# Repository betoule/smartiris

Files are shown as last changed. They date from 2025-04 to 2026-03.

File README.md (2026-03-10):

SmartIris USB-Powered Shutter Controller
========================================

A compact and efficient USB-powered controller designed to handle two
independent Iris shutters by
[Thorlabs](https://www.thorlabs.com/newgrouppage9.cfm?objectgroup_id=6619&pn=SHB1T#7096). This
project offers an alternative solution that avoids heat dissipation,
sending only the necessary current pulses to open or close the
shutter. This alternative is suitable for low actuation rates (~1Hz), where timing accuracy matters.

Features
--------

* Easy-to-use USB interface for power and control
* Open-source design for customization
* Programmable coordinated channels for two Iris shutters
* Python library
* Improved energy efficiency by avoiding continuous heat dissipation
* Internal clock calibration for accurate timings
* Half-microsecond resolution on timings
* Timing of the iris movements via sensor feedback
* Echo the sensor feedback signal on a trig-out line
* Possibility to echo the pulse commands on the trig-out line

Getting Started
---------------

### Requirements

* One or Two Thorlabs Iris shutters
* USB A to Mini-B cable
* 3D printed or custom PCB case (optional)

### Software Installation

1. Download and install the control software for your operating system from the project's GitHub repository:
```bash
git clone https://github.com/betoule/smartiris.git
cd smartiris
pip install .
```
2. Connect the controller to your computer via a USB port using a USB A to Mini-B cable.
3. Ensure that an Iris shutters is properly connected to the controller with matching channel assignments. Port "A" and "B" refers to the left and right port respectively.
4. Test the status:
```bash
smartiris status
```
Example output for two closed and connected shutters:
```
{'shutter_A': 'closed', 'shutter_B': 'closed', 'busy': False}
```

Unconnected shutters appear as `closed`. Partly open shutters may appear as closed or open depending on the sensor location on the device.

The button can be used to switch the shutters on and off. They have precedence upon the software control, meaning that if a timed exposure as been programmed, pressing any of the button will interrupt the program and close or open the corresponding shutter. If needed button can be deactivated by software.

### Troubleshooting

#### Permission errors 

Errors of the kind:
```
PermissionError: [Errno 13] Permission denied: '/dev/serial/by-id/usb-FTDI_FT232R_USB_UART_AQ01L27T-if00-port
```
occur when you don't have access rights to the serial devices. On linux systems you need to add yourself to the dialout group:
```bash
sudo usermod -a -G dialout username
```
Group changes typically take effect after the user logs out and logs back in. To apply the change immediately without logging out, you can use
```bash
newgrp dialout
```

#### FileNotFound errors

Errors of the kind:
```
FileNotFoundError: [Errno 2] No such file or directory: '/dev/serial/by-id/usb-FTDI_FT232R_USB_UART_AQ01L27T-if00-port0'
```
occur when the serial device is not at the spectified location. You need to identify the path to the device file by looking at appearing files in:
```bash
ls /dev/serial/by-id/
#plug the device
ls /dev/serial/by-id/
#Look for the new line
```
after the device has been plugged. Once the device has been identified you can specify its path as:
```bash
smartiris -t /dev/serial/by-id/{actual_device_id} status
```

Mac-OS users should look for the device appearing in:
```bash
ls /dev/tty*.*
```

### Hardware build

* Schematics is available in directory `schematics`
* Files to build a 3D case are available in `3D`
* Once assembled connect your computer to the arduino and flash the firmware using the arduino IDE. The code is compatible with version 1.8 of the IDE. Open the sketch `smartiris.ino` and upload the sketch.

Usage
-----
### Command line

The `smartiris` command-line tool controls supports several commands and options to operate the shutter.

#### Basic Syntax
```
smartiris [OPTIONS] COMMAND
```

#### Options
- `-t, --tty PORT`  
  Specify the TTY port (default: `""` attempt to autodetect the relevant serial device).
- `-w, --pulse-width SECONDS`  
  Set the duration of opening/closing pulses in seconds (default: `0.03`).
- `-p, --port ID`  
  Select the shutter port (default: `A`).
- `-v, --verbose`  
  Enable debug output for communication.
- `-r, --reset`  
  Perform a hard reset of the device on startup. The execution of the command is slower at first call.

#### Commands
- `open`  
  Open the shutter.  
  Example: `smartiris open`

- `close`  
  Close the shutter.  
  Example: `smartiris close`

- `timed`  
  Open the shutter for a specified duration.  
  Additional options:  
  - `-d, --delay SECONDS`  
    Delay before action (default: `0.01` seconds).  
  - `-e, --exposure-time SECONDS`  
    Duration to keep the shutter open (default: `1.0` seconds).  
  Example: `smartiris timed -e 2.5`

- `stop`  
  Interrupt execution, leaving the shutter in its current state.  
  Example: `smartiris stop`

- `status`  
  Display the current status of the shutter driver.  
  Example: `smartiris status`

- `disable_button`  
  Disable the on-board buttons to avoid interference with remote controle

- `enable_button`  
  Re-enable the on-board buttons. They will have precedence over remote operations

#### Examples
- Open the shutter with a custom pulse width on port B:  
  `smartiris -p B -w 25 open`
- Keep the shutter open for 3 seconds:  
  `smartiris timed -e 3.0`
- Same thing, this time echoing the pulse signals (relevant when the feedback sensor is cooked):  
  `smartiris timed -e 3.0 --echo`
- Check the shutter status with verbose output of the communication with the device:  
  `smartiris -v status`
- Interrupt a long duration exposure. The shutter will remain in its current state.
  ```
  smartiris timed -e 10
  sleep 0.1
  smartiris status
  smartiris stop
  smartiris status
  ```
- Run a 1 minute calibration of the internal clock of the device for accurate timing:  
  `smartiris calibrate -d 1`
  
### Python library

The python library provides direct access to the controler. The control logic works as follows: a short program is written to the controler specifying which pins to operate at specific timings to energize the activation coils of the shutters. The timing are specified with a resolution of 0.5μs and can extend over a duration of up to 17 minutes. The high level functions are `open_shutter` and `close_shutter` which execute a two step program (energize the coil for a given duration then release) and `timed_shutter` which executes a 4 step program chaining the two operations separated by a given interval. All writen program executions can be prevented by specifying `exec=False` then triggered latter at will by calls to `start_program`. The use of delayed execution avoid cummulating random delays in the USB communication and offer the best synchronisation timing between the host and the device. Here is a complete example illustrating the various functions of the library:

```python
import smartiris

print('Connect to the device')
# If a single device is connected, there is no need to specify the device
d = smartiris.SmartIris()

print(' Query the shutter status')
print(d.status())

print('Open the port A shutter')
d.open_shutter()
print('Wait for completion')
d.wait()

print('Close port A shutter')
d.close_shutter()
print('Wait for completion')
d.wait()
,
print('Open for 3 seconds after a 2 seconds delay (setup only)')
d.timed_shutter(delay_sec=2, duration_sec=3)
print('Wait for completion')
d.wait()

print('re-trigger')
d.start_program()
print('Wait for completion')
d.wait()

# If the feedback sensor is not working, one can echo the control pulses on the trigger line instead
d.timed_shutter(delay_sec=2, duration_sec=3, echo=True)
d.wait()
```
	
Roadmap
-------

- [ ] Record the timings of the hall sensor trigger
- [ ] Handle manual operation
- [ ] Robustify the serial communication

Release History
---------------
### v0.3.1
- When the shutter position sensor is cooked, it can be convenient to echo the pulse signals on the trigout
### v0.3.0
- Implement a calibration procedure for the MCU clock enabling accurate timings

### v0.2.0
- Handle button event
- Pull-up sensor lines to make unconnected shutter consistently appear as close
- Auto-detect the device port

### v0.1.0
First release in use during the april 2025 OHP campaign

Contributing
------------

Main contributors are:
- Marc Betoule, for the firmware and the host python library
- Fabien Frerot, for the electronics and schematics

Pull requests are welcome! For major changes, please open an issue first to discuss proposed modifications.

License
-------

This project is licensed under GPL V2 License - see the [LICENSE.md](LICENSE.md) file for details.

Acknowledgments
--------------

* Thorlabs for manufacturing quality Iris shutters
* Open-source community for valuable contributions and support

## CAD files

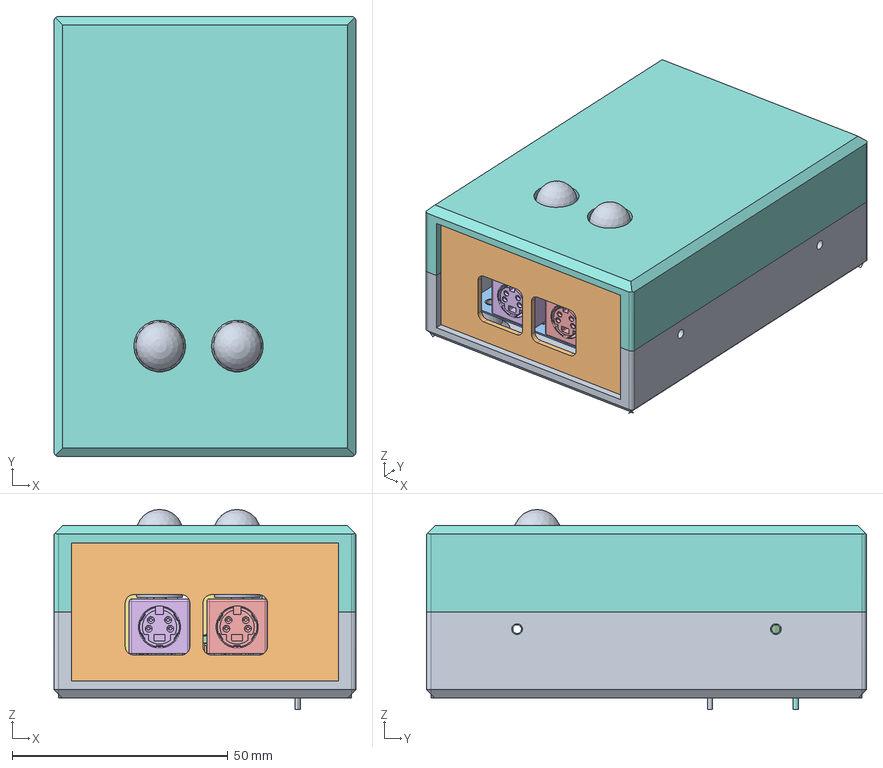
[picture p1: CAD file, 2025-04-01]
3D/box.FCStd
70.0 x 102.0 x 46.4 mm
Bottom
Front
R603
C0603
R604
C0604
AVX Logo 2
AVX Logo 003
AVX Logo 004
AVX Logo 005
AVX Logo 006
AVX Logo 007
AVX Logo 008
AVX Logo 009
AVX Logo 010
DO-201AD
DO-201AD001
DO-201AD002
DO-201AD003
RESISTOR_2W_VERTICALE
RESISTOR_2W_VERTICALE001
RESISTOR_2W_VERTICALE002
RESISTOR_2W_VERTICALE003
CAP_RN_10X20_NCH
CAP_RN_10X20_NCH001
CAP_RN_10X20_NCH002
CAP_RN_10X20_NCH003
CAP_RN_10X20_NCH005
CAP_RN_10X20_NCH006
CAP_RN_10X20_NCH007
CAP_RN_10X20_NCH008
CAP_RN_10X20_NCH010
CAP_RN_10X20_NCH011
CAP_RN_10X20_NCH012
CAP_RN_10X20_NCH013
CAP_RN_10X20_NCH015
CAP_RN_10X20_NCH016
CAP_RN_10X20_NCH017
CAP_RN_10X20_NCH018
arm
leads
leads001
leads002
leads003
top
TE Connectivity
TE Connectivity001
TE Connectivity002
TE Connectivity003
TE Connectivity004
TE Connectivity005
TE Connectivity006
TE Connectivity007
TE Connectivity008
TE Connectivity009
TE Connectivity010
TE Connectivity011
TE Connectivity012
TE Connectivity013
TE Connectivity014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

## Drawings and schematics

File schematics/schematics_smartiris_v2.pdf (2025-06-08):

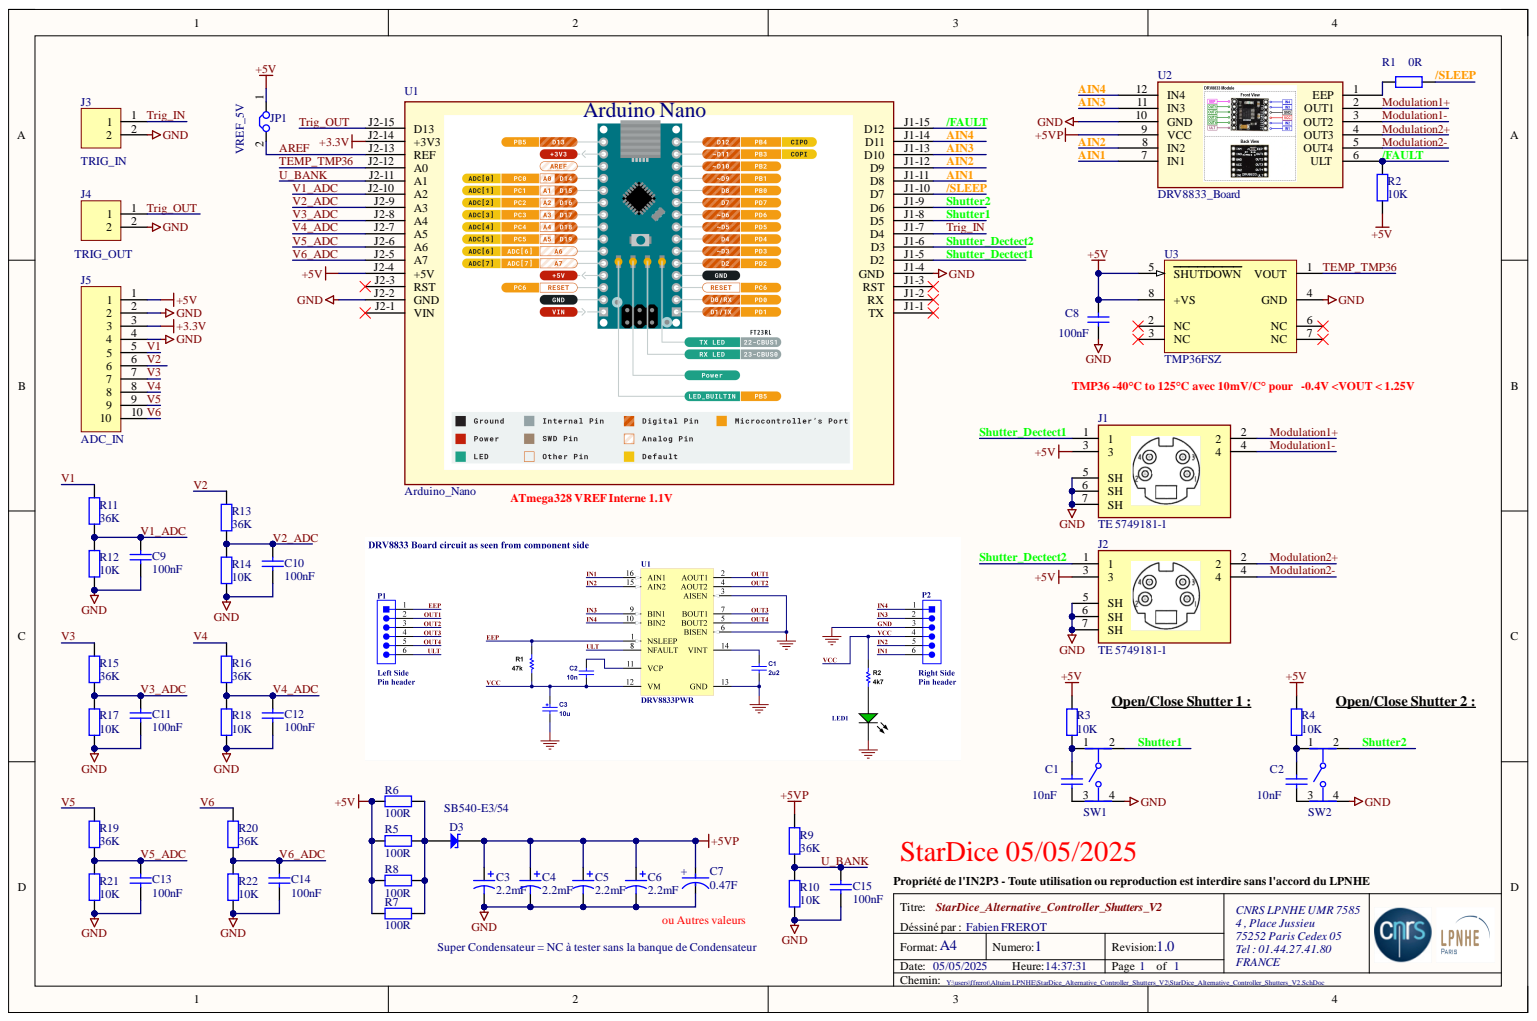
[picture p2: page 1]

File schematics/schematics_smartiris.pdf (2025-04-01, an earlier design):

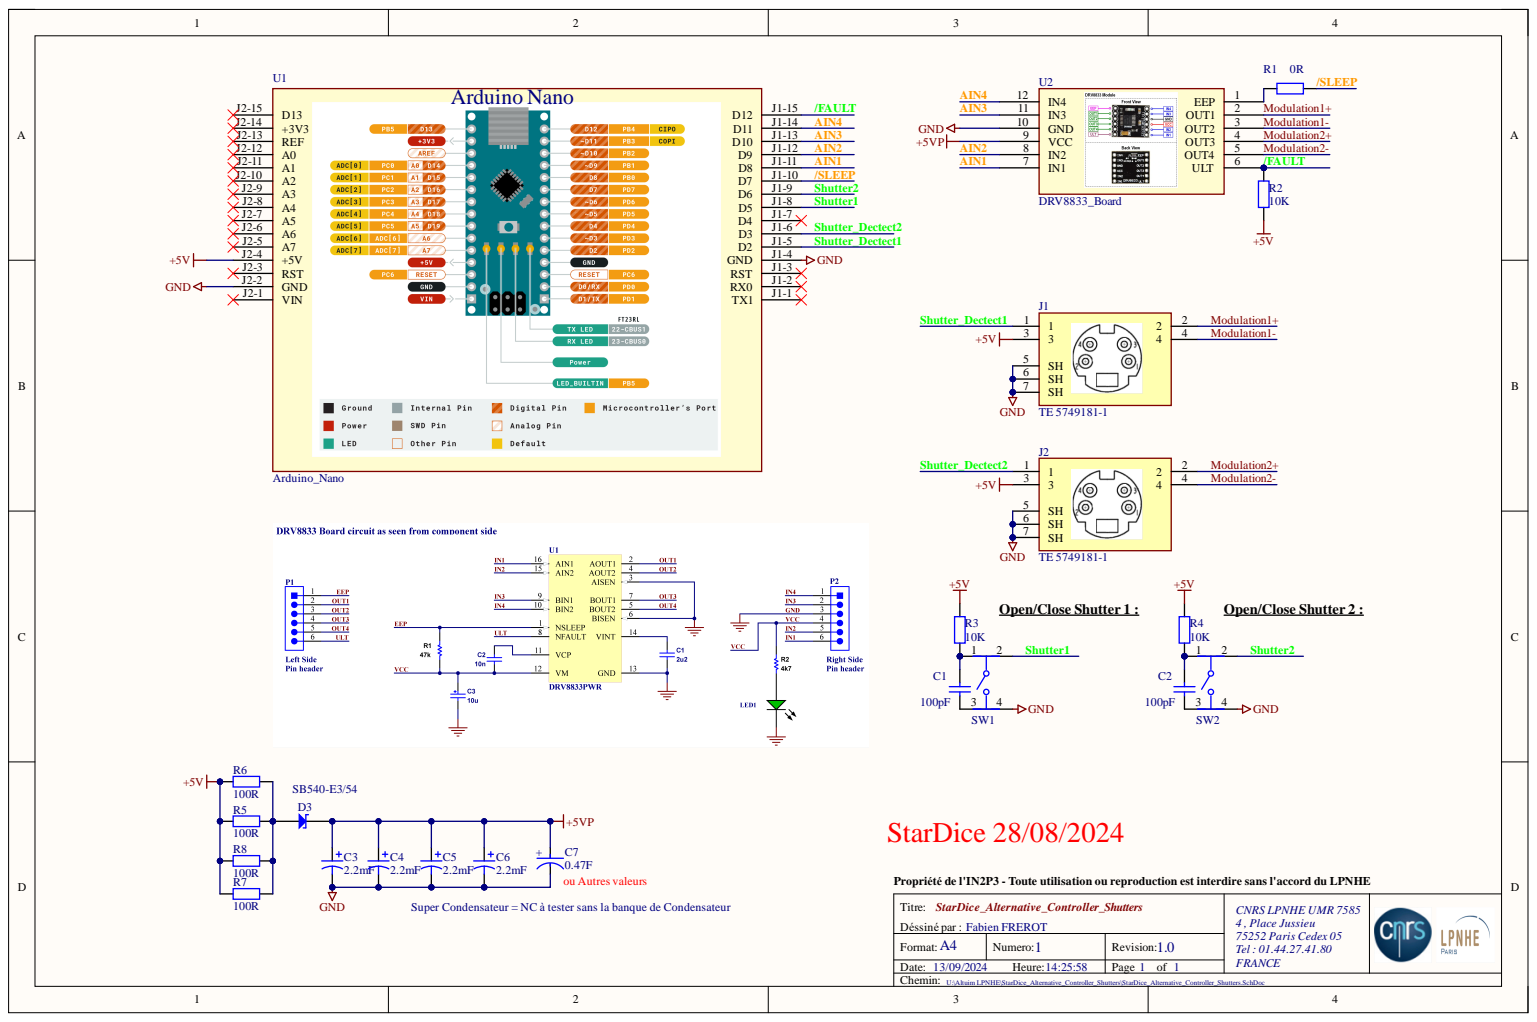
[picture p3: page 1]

Propriété de l'IN2P3 - Toute utilisation ou reproduction est interdire sans l'accord du LPNHE

Super Condensateur = NC à tester sans la banque de Condensateur

Titre:
Déssiné par : Fabien FREROT
Chemin:

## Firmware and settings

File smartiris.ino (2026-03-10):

// Copyright 2024-2025 Marc Betoule
// 
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
#include <Arduino.h>
#include "bincoms.h"
#include <EEPROM.h>

/* The main fonction of the API. Send a pulse of a given duration on
   the given line.
 */ 
void program_pulse(uint8_t rb);
void start_program(uint8_t rb);
void stop_program(uint8_t rb);
void get_program(uint8_t rb);
void status(uint8_t rb);
void set_interrupt_mask(uint8_t rb);
void start_timer(uint8_t rb);
void get_time(uint8_t rb);
void get_clock_calibration(uint8_t rb);
void set_clock_calibration(uint8_t rb);
void read_adc(uint8_t rb);
void read_signature_row(uint8_t rb);
void switch_button();

uint32_t duration;
uint16_t duration_HB;
uint16_t duration_LB;
uint16_t timeHB;
uint8_t pin;

// The maximum number of programmable control pin changes
const uint8_t MAX_N_EVENTS=16;
// The maximum number of recordable events
const uint8_t MAX_N_RECORDS=16; 

uint8_t n_events;
uint8_t event = 0;
typedef struct {
  uint16_t time_LB;
  uint16_t time_HB;
  uint8_t pin;
} Event;

Event * active_program;
uint8_t active_nevent;

// This store the program
Event program[MAX_N_EVENTS];

// Those are 4 builtin programs to open and close the two shutters when the button are activated
Event OpenA[2] = {{20000, 0x0, 0b10}, {0x5f90, 1, 0b10}};
Event CloseA[2] = {{20000, 0x0, 0b1}, {0x5f90, 1, 0b1}};
Event OpenB[2] = {{20000, 0x0, 0b1000}, {0x5f90, 1, 0b1000}};
Event CloseB[2] = {{20000, 0x0, 0b100}, {0x5f90, 1, 0b100}};

// To record sensor event timings
Event sensor_timing_record[MAX_N_RECORDS];
uint8_t n_record = 0;

// Generic record interrupt handler. This interrupt handler need to
// handle timing rollover internally because it could mask the overflow
// interrupt and record incorrect timing because of that.
#define INTERRUPT_HANDLER(line)                                    \
  sensor_timing_record[n_record].time_LB = TCNT1;                   \
  PINB |= _BV(PB5);                                                  \ 
  if ((TIFR1 & 0b1) && (sensor_timing_record[n_record].time_LB < 10)){\
    timeHB++;							   \
    TIFR1 |= _BV(TOV1);						   \
  }								   \
  sensor_timing_record[n_record].pin = line;			   \
  sensor_timing_record[n_record].time_HB = timeHB;                  \
  if (n_record < MAX_N_RECORDS - 1) n_record++;                    \
  
// Macros to start and stop the 16-bit timer
#define STOP_TIMER TCCR1B = 0b00000000
#define START_TIMER TCCR1B = 0b00000010
// enable overflow and compare match A interupts on the 16 bit timer
#define ENABLE_INT TIMSK1 = 0b00000011
// Disable overflow and compare interrupts on the 16bit timer
#define DISABLE_INT TIMSK1 = 0b00000000
#define CLEAR_INT TIFR1 = _BV(OCF1A)

const uint8_t NFUNC = 2+12;
uint8_t narg[NFUNC];
// The exposed functions
void (*func[NFUNC])(uint8_t rb) =
  {// Communication protocol
   command_count,
   get_command_names,
   // user defined
   program_pulse,
   start_program,
   stop_program,
   get_program,
   status,
   set_interrupt_mask,
   start_timer,
   get_time,
   get_clock_calibration,
   set_clock_calibration,
   read_adc,
   read_signature_row,
  };

const char* command_names[NFUNC*3] =
  {"command_count", "", "B",
   "get_command_names", "BB", "s",
   // user defined
   "program_pulse", "BBI", "I",
   "start_program", "", "",
   "stop_program", "", "",
   "get_program", "BB", "IB",
   "raw_status", "", "BBBBB",
   "_set_interrupt_mask", "B", "",
   "_start_timer", "", "",
   "get_time", "", "I",
   "get_clock_calibration", "", "f",
   "set_clock_calibration", "f", "",
   "read_adc", "B", "H",
   "read_signature_row", "H", "B",
  };


void setup(){
  // Setup fast binary remote procedure call library
  setup_bincom();

  // Nano assignments
  // PORTB dedicated to outputs, PORTD to inputs

  // PORTB setup for output on arduino pin 8-13 (PB0 - PB5)
  DDRB   = _BV(PB0) | _BV(PB1) | _BV(PB2) | _BV(PB3) | _BV(PB4)| _BV(PB5);
  PORTB  = ~(_BV(PB0) | _BV(PB1) | _BV(PB2) | _BV(PB3) | _BV(PB4)| _BV(PB5));
  
  // PORTD used as input:
  // PD2/3 shutter detection line
  // PD4 free (for TTL ?)
  // PD5/6 button detection (PCINT21/22)
  // PD7 /sleep
  // setup for inputs
  DDRD &= ~(_BV(PD2) | _BV(PD3) | _BV(PD4) | _BV(5) | _BV(PD6));
  // Pull-up
  PORTD = (_BV(PD2) | _BV(PD3) | _BV(PD4) | _BV(5) | _BV(PD6));
  // Button detection
  PCMSK2 = _BV(PCINT21) | _BV(PCINT22);
  PCMSK0 = 0b00000000;
  PCICR = _BV(PCIE2);
  // Setup external interrupt as pin change interrupt for arduino pin D2 and D3
  EICRA = 0b0101;
  // Setup external interrupt rise for arduino pin 2 and 3 (INT0 and INT1)
  //EICRA |= _BV(ISC11) | _BV(ISC10) | _BV(ISC01) | _BV(ISC00);  
  //SET_TIMER1_CLOCK(TIMER_CLOCK_1);
  // 16-bit TIMER1 settings
  // This timer is used to follow the clock count
  // TCCR1A: COM1A1:COM1A0:COM1B1:COM1B0:0:0:WGM11:WGM10
  // TCCR1B: ICNC1:ICES1:0:WGM13:WGM12:CS12:CS11:CS10
  // TIMSK1: 0:0:ICIE1:0:0:OCIE1B:OCIE1A:TOIE1
  // COM1A: 0b01 toggle on compare match
  // COM1B: 0b01 toggle on compare match
  // WGM: 0b0100 CTC
  // WGM: 0b0000 Normal
  // CS1: 0b000 STOP
  TCCR1A = 0b00000000;
  STOP_TIMER;
  DISABLE_INT;
  
  // We disable the awful clock of the arduino IDE
  TCCR0B = 0b0;
  TIMSK0 = 0b0;
  TCCR2B = 0b0;
  TIMSK2 = 0b0;
  EIMSK = 0b0;

  // Port C used as inputs (ADC)
  DDRC = 0b00000000;
  // Disable pull-ups
  PORTC = 0;
  
  // Configure ADCSRA: Enable ADC, set prescaler to 128 (assuming 8–16 MHz clock)
  ADCSRA = _BV(ADEN) | _BV(ADPS2) | _BV(ADPS1) | _BV(ADPS0);
 
}




// Update high bytes of the timer counter
ISR(TIMER1_OVF_vect){
  timeHB++;
}

void _stop_program(){
  STOP_TIMER;
  DISABLE_INT;
  EIMSK = 0b0;
  event = 0;
  PORTB = 0;
}

// Timer Interruption handling
ISR(TIMER1_COMPA_vect){
  // Emulate 32 bit resolution by executing the code only if the high
  // bytes of the timer counter also match. The additionnal 16 bit
  // comparison adds a small (but constant) delay to the pin change.
  if (timeHB == active_program[event-1].time_HB){
    PINB = active_program[event-1].pin;
    if (event == active_nevent){
      _stop_program();
    }
    else{
      OCR1A = active_program[event].time_LB;
      event++;
    }
  }
}


// Button activation handling
ISR(PCINT2_vect){
  //PINB = _BV(PB5);
  switch_button();
}

// sensor detection on arduino pin D2
ISR(INT0_vect){
  INTERRUPT_HANDLER(0b1)
}
// sensor detection on arduino pin D3
ISR(INT1_vect){
  INTERRUPT_HANDLER(0b10)
}

void loop(){
  // This shunt the arduino loop
  client.serve_serial();
}

void set_interrupt_mask(uint8_t rb){
  /* This function can be used to enable/disable the button interrupt
   *
   * The function read the mask as 1 uint8_t argument from the communication buffer:
   */
    PCMSK2 = *((uint8_t *) (client.read_buffer + rb));
    client.sndstatus(STATUS_OK);
}

void program_pulse(uint8_t rb){
  /* Program one slot of the pulse program
   *
   * The function reads 3 arguments from the communication buffer:
   * pin: the portB mask to select which pin to switch (Byte)
   * n_events: (Byte) the slot number in the program between 0 and MAX_N_EVENTS - 1
   * duration: (int) the timing of the switch in counts since the launch of the program. A count as a value of 0.5e-6 seconds.
   */
  client.readn(&rb, &pin, 1);
  client.readn(&rb, &n_events, 1);
  // We receive the duration as timer count with a resolution of
  // 0.5e-6s
  client.readn(&rb, (uint8_t*) &duration, 4);
  //pin = *((uint8_t *) (client.read_buffer + rb));
  //n_events = *((uint8_t *) (client.read_buffer + rb+1));
  //duration = *((uint32_t *) (client.read_buffer + rb + 2));
  if (n_events >= MAX_N_EVENTS){
    client.snd((uint8_t*) &duration, 4, VALUE_ERROR);
    return;
  }
  if (pin & 11000000){
    client.snd((uint8_t*) &duration, 4, VALUE_ERROR);
    return;
  } 
  else
    client.snd((uint8_t*) &duration, 4);

  // set up the pin sequence
  // We receive directly the pin mask
  program[n_events].pin = pin;
  //Convert pin number to bit position
  //program[n_events].pin = 1 << pin;

  // set up the timings
  program[n_events].time_LB = duration & 0xFFFF;
  program[n_events].time_HB = duration >> 16;
  n_events++;
}

void get_program(uint8_t rb){
  /* Query a slot of the pulse program
   *
   * The function reads 2 arguments from the communication buffer:
   * i: (Byte) the slot number in the program between 0 and MAX_N_EVENTS - 1
   * p: (Byte) the index of the program to read
   * It returns 2 values to the communication buffer:
   * duration: (Int) the timing of the pulse in slot i (in counts)
   * pin: (Byte) the index of the pin switched in the PORTB
   */
  uint8_t data[5];
  uint8_t i = *((uint8_t *) (client.read_buffer + rb));
  uint8_t program_num = *((uint8_t *) (client.read_buffer + (rb + 1)));
  Event * program_slot;
  if (program_num == 1)
    program_slot = sensor_timing_record;
  else
    program_slot = program;
  duration = program_slot[i].time_HB;
  duration <<= 16;
  duration += program_slot[i].time_LB;
  *((uint32_t*)(data)) = duration;
  data[4] = program_slot[i].pin;
  client.snd((uint8_t*) data, 5, STATUS_OK);
}

void _start_program(){
  // Split that into a high and low resolution part
  OCR1A = active_program[0].time_LB;

  // Reset the timer
  timeHB=0;
  TCNT1=0;
  CLEAR_INT;
  n_record=0;
  EIMSK = 0b11;
  ENABLE_INT;
  START_TIMER;
}

void start_program(uint8_t rb){
  /* Start the execution of the pulse program
   */
  event = 1;
  active_program = program;
  active_nevent = n_events;
  _start_program();
  client.sndstatus(STATUS_OK);
}

void start_timer(uint8_t rb){
  /* Start the timer execution without program
    (Usually used for clock calibration purpose)
   */
  _stop_program();
  // Reset the timer
  timeHB=0;
  TCNT1=0;
  CLEAR_INT;
  // Enable timer overflow but not the other instructions
  TIMSK1 = 0b00000001;
  START_TIMER;
  client.sndstatus(STATUS_OK);
}

void get_time(uint8_t rb){
  duration = timeHB;
  duration <<= 16;
  duration += TCNT1;
  client.snd((uint8_t*) &duration, 4, STATUS_OK);
}

void stop_program(uint8_t rb){
  /* Stop the program exectution
   */
  _stop_program();
  client.sndstatus(STATUS_OK);
}

void status(uint8_t rb){
  /* Return the status of device
   *
   * The function return 4 bytes to communication buffer:
   * PINB the state of the 8 GPIO pins in Port B
   * PIND the state of the 8 GPIO pins in Port D
   * event the current index of the slot in program
   * n_events the length of the program
   * the number of recorded events
   */
  uint8_t data[5];
  data[0] = PINB;
  data[1] = PIND;
  data[2] = event;
  //data[3] = n_events;
  data[3] = active_nevent;
  data[4] = n_record;
  client.snd((uint8_t*) &data, 5, STATUS_OK);
}

void get_clock_calibration(uint8_t rb){
  float calibration_constant = 2e6;
  EEPROM.get(0, calibration_constant);
  client.snd((uint8_t*) &calibration_constant, 4, STATUS_OK);
}

void set_clock_calibration(uint8_t rb){
  float calibration_constant = 2e6;
  client.readn(&rb, (uint8_t*) &calibration_constant, 4);
  EEPROM.put(0, calibration_constant);
  client.sndstatus(STATUS_OK);
}

void read_adc(uint8_t rb){
  uint8_t channel = *((uint8_t *) (client.read_buffer + rb));
  // ADCSRA reference:
  // ADEN-ADSC-ADATE-ADIF-ADIE-ADPS2-ADPS1-ADPS0
  
  // Configure ADMUX: Internal 1.1V reference, right-adjusted result, select channel
  ADMUX = _BV(REFS1) | _BV(REFS0) | (channel & 0x0F);

  // Start first conversion
  ADCSRA |= (1 << ADSC);

  // Wait for conversion to complete
  while(ADCSRA & _BV(ADSC));// ADSC is cleared when conversion finishes

  // Read ADC result (read ADCL first, then ADCH)
  uint16_t result = ADCL; // Read low byte first
  result += (ADCH<<8); // Read high byte and combine
  
  client.snd((uint8_t *) &result, 2, STATUS_OK);
}


void switch_button(){
  //if (event == 0){
  _stop_program();
  if (!(PIND & 0b100000)){//buttonA
    if (PIND & 0b100) //closed
      {
	event = 1;
	active_program = OpenA;
	active_nevent = 2;
	_start_program();
      }
    else
      {
	event = 1;
	active_program = CloseA;
	active_nevent = 2;
	_start_program();
      }
  }
  else if (!(PIND & 0b1000000)){//buttonB
    if (PIND & 0b1000) //closed
      {
	event = 1;
	active_program = OpenB;
	active_nevent = 2;
	_start_program();
      }
    else
      {
	event = 1;
	active_program = CloseB;
	active_nevent = 2;
	_start_program();
      }
  }
}

void read_signature_row(uint8_t rb) {
    uint8_t result;
    uint16_t address;
    client.readn(&rb, (uint8_t*) &address, 2);
    
    // Disable interrupts to ensure atomic operation
    cli();

    // Wait for any ongoing SPM/EEPROM operations to complete
    while (SPMCSR & (1 << SPMEN));

    // Set SIGRD and SPMEN to enable signature row read
    SPMCSR = (1 << SIGRD) | (1 << SPMEN);
    
    // Load the address into Z register (R31:R30) and read using LPM
    asm volatile("lpm %1, Z" "\n\t"    // Read byte from program memory at Z into result
		 : "=r" (result)        // Output: result
		 : "z" (address)   // Input: address (shifted left by 1 for word addressing)
		 );

    // Clear SPMCSR
    SPMCSR = 0;

    // Re-enable interrupts
    sei();

    client.snd(&result, 1, STATUS_OK);
}

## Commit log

2024-08-05 sketch the arduino code
2025-04-01 add 3D files
    [box.FCStd]
2025-04-01 add schematics
2025-04-02 attempt to deal with buttons
2025-04-09 raise meaningful errors when no or more than one devices are found
2025-04-09 have one button working
2025-04-09 get second button working
2025-04-09 fix outstanding bug in the multi-program handling
    [smartiris.ino]
2025-04-09 make it possible to disable on-board buttons
2025-04-09 fix outstanding communication bug
    [smartiris.ino]
2025-04-09 equip the firmware to read and write the clock calibration constant to the eeprom
2025-04-09 implement the calibration procedure
2025-04-11 add testing material for timing, reliability and clock calibration
2025-06-08 add adc reading capabalities for v2 version
2025-06-09 implement reading of mcu temperature sensor
2025-12-19 temperature reading in clock calibration

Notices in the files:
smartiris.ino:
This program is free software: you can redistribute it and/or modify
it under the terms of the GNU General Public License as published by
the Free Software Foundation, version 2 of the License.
